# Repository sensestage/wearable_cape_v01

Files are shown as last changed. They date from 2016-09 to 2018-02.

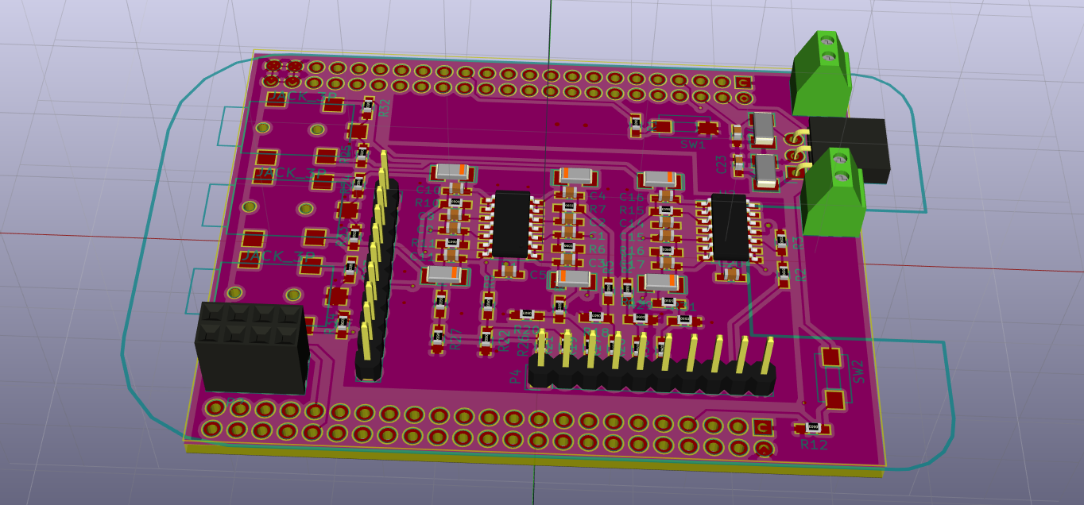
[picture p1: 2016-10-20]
wearable_cape_v0.2.png

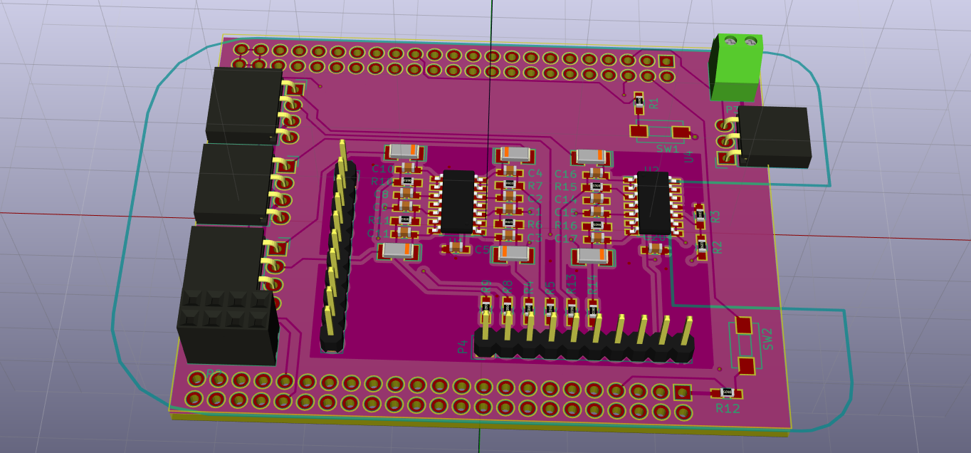
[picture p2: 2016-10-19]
wearable_cape.png

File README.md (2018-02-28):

# wearable_cape_v01

First version of a wearable cape for the VanAbbemuseum Earthquake Archive

## ToDos

### Minor fixes for v02

- fix wiring errors on minijack outputs to amplifiers
- Swap out the buffered voltage divider 1.8V reference for a fixed regulator
- Add bypass capacitors to the active filters
- widen power rail traces to the amplifier boards
- silkscreen labels for switch functionality and outputs
- breakout capability of mode switch, reset switch, & status LEDs
  - user leds, see: http://beaglebone.cameon.net/home/using-the-user-leds

### Larger improvements

- add additional 2-channel output for full access to all output channels

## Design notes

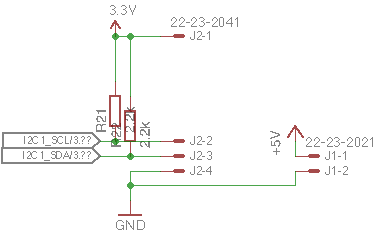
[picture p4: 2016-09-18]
Documentation/Bela_Cape_Schematic04.png

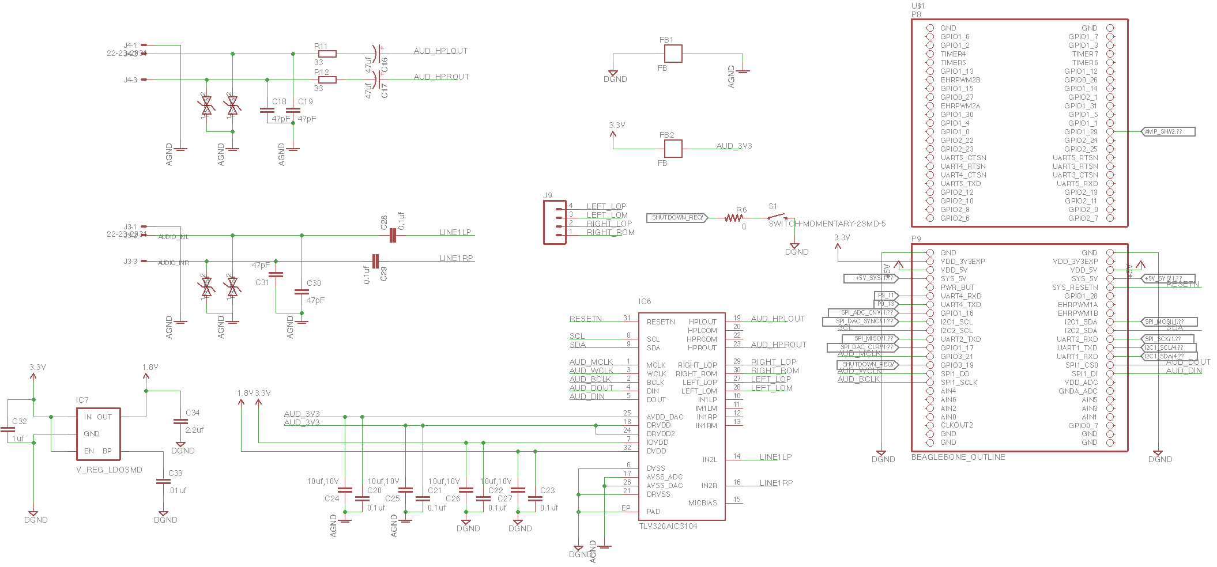
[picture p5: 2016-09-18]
Documentation/Bela_Cape_Schematic03.png

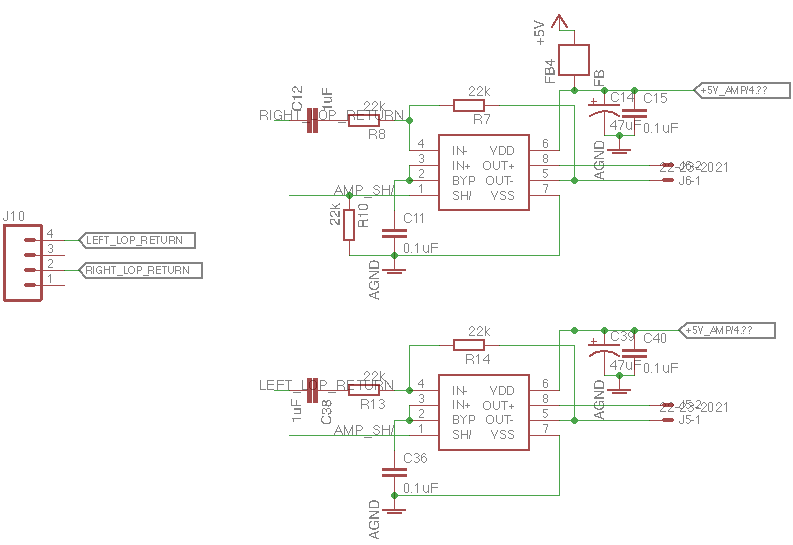
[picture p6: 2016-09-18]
Documentation/Bela_Cape_Schematic02.png

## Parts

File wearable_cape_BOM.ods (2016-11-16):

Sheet: References
Reference | Value | Library | Library Ref
R1 | 100 | device | R
C20 | 100nF | device | C
C5 | 100nF | device | C
R12 | 10k | device | R
R2 | 120k | device | R
C12 | 1uF | device | CP1
C13 | 1uF | device | CP1
C18 | 1uF | device | CP1
C19 | 1uF | device | CP1
C6 | 1uF | device | CP1
C7 | 1uF | device | CP1
C1 | 220pF | device | C
C14 | 220pF | device | C
C15 | 220pF | device | C
C2 | 220pF | device | C
C8 | 220pF | device | C
C9 | 220pF | device | C
R10 | 28.7k | device | R
R11 | 28.7k | device | R
R13 | 28.7k | device | R
R14 | 28.7k | device | R
R15 | 28.7k | device | R
R16 | 28.7k | device | R
R4 | 28.7k | device | R
R5 | 28.7k | device | R
R6 | 28.7k | device | R
R7 | 28.7k | device | R
R8 | 28.7k | device | R
R9 | 28.7k | device | R
C10 | 440pF | device | C
C11 | 440pF | device | C
C16 | 440pF | device | C
C17 | 440pF | device | C
C3 | 440pF | device | C
C4 | 440pF | device | C
R3 | 68k | device | R
P3 | BATTERY | conn | CONN_01X02
U3 | BEAGLEBONEBLACK | beagleboneblack | BEAGLEBONEBLACK
P1 | BELA_AINS | wearable_cape | BELA_AINS
P4 | BELA_AOUTS | wearable_cape | BELA_AOUTS
P5 | CONN_01X04 | conn | CONN_01X04
P6 | CONN_01X04 | conn | CONN_01X04
P7 | CONN_01X04 | conn | CONN_01X04
U1 | MCP6004 | linear | MCP6004
U2 | MCP6004 | linear | MCP6004
U4 | OKI_7805 | oki_7805 | OKI_7805
P2 | RECEIVER | conn | CONN_02X04
SW1 | SW_HALT | device | SW_PUSH
SW2 | SW_MODE_SEL | device | SW_PUSH
C21 | CP1 | device | CP1
C22 | CP1 | device | CP1
P5 | PWR_OUT | conn | CONN_01X02
J1 | JACK_3P | jack_3p | JACK_3P
J2 | JACK_3P | jack_3p | JACK_3P
J3 | JACK_3P | jack_3p | JACK_3P
C23 | C | device | C
C24 | C | device | C
R23 | 100k | device | R
R25 | 100k | device | R
R24 | 100k | device | R
R34 | 100k | device | R
R32 | 100k | device | R
R33 | 100k | device | R
R19 | 150k | device | R
R20 | 200k | device | R
R17 | 150k | device | R
R18 | 200k | device | R
R21 | 150k | device | R
R22 | 200k | device | R
R30 | 150k | device | R
R31 | 200k | device | R
R28 | 150k | device | R
R29 | 200k | device | R
R26 | 150k | device | R
R27 | 200k | device | R

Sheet: BOM
 |  |  |  |  |  |  |  |  |  | € 83,7804 | boards | 4
References | Value | Amount | Footprint | Supplier | Supplier part no | Cost/unit | Cost/N | N | Minimum N | Total cost / board | in stock (pre 15-11) | needed | Part no. | to order | Ordered 7-11 | Ordered 15-11
R1 | 100 | 1 | R0603 | Farnell | 2447227 | € 0,0035 | € 0,04 | 10 | 10 | € 0,0035 | 10 | 4 | 2447227 | 0 | 10
R18, R20, R22, R27, R29, R31 | 390 | 6 | R0603 | Farnell | 2447353 | € 0,0035 | € 0,04 | 10 | 10 | € 0,0210 | 20 | 24 | 2447353 | 4 | 20 | 10
R17, R19, R21, R26, R28, R30 | 2k2 | 6 | R0603 | Farnell | 2447320 | € 0,0035 | € 0,04 | 10 | 10 | € 0,0210 | 20 | 24 | 2447320 | 4 | 20 | 10
R23, R24, R25, R32, R33, R34 | 3k9 | 6 | R0603 | Farnell | 2447359 | € 0,0035 | € 0,04 | 10 | 10 | € 0,0210 | 20 | 24 | 2447359 | 4 | 20 | 10
R12 | 10k | 1 | R0603 | Farnell | 2447230 | € 0,0035 | € 0,04 | 10 | 10 | € 0,0035 | 10 | 4 | 2447230 | 0 | 10
R35, R36, R37, R38, R39, R40 | 12k | 6 | R0603 | Farnell | 2447243 | € 0,0035 | € 0,04 | 10 | 10 | € 0,0210 | 20 | 24 | 2447243 | 4 | 20 | 10
R2 | 120k | 1 | R0603 | Farnell | 2447239 | € 0,0035 | € 0,04 | 10 | 10 | € 0,0035 | 10 | 4 | 2447239 | 0 | 10
R10, R11, R13, R14, R15, R16, R4, R5, R6, R7, R8, R9 | 28.7k | 12 | R0603 | Farnell | 2447318 | € 0,0036 | € 0,04 | 10 | 10 | € 0,0432 | 40 | 48 | 2447318 | 8 | 40 | 10
R3 | 68k | 1 | R0603 | Farnell | 2447420 | € 0,0035 | € 0,04 | 10 | 10 | € 0,0035 | 10 | 4 | 2447420 | 0 | 10
 | 100k | 0 | R0603 | Farnell | 2447226 | € 0,0035 | € 0,04 | 10 | 10 | € 0,0000 |  | 0 | 2447226 | 0
 | 150k | 0 | R0603 | Farnell | 2447254 | € 0,0037 | € 0,04 | 10 | 10 | € 0,0000 |  | 0 | 2447254 | 0
 | 200k | 0 | R0603 | Farnell | 2447291 | € 0,0035 | € 0,04 | 10 | 10 | € 0,0000 |  | 0 | 2447291 | 0
FB1, FB2 | Ferrite bead | 2 | R0603 | Farnell | 1781090 | € 0,0608 | € 0,06 | 1 | 10 | € 0,1216 | 10 | 8 | 1781090 | 0 | 10
C5, C20 | 100nF | 2 | C0603 | Farnell | 1740612 | € 0,0531 | € 0,53 | 10 | 10 | € 0,1062 | 10 | 8 | 1740612 | 0 | 10
C6, C7, C12, C13, C18, C19 | 1uF | 6 | C1206 | Farnell | 1759436 | € 0,0587 | € 0,59 | 10 | 10 | € 0,3522 | 20 | 24 | 1759436 | 4 | 20 | 10
C1, C2, C8, C9, C14, C15 | 220pF | 6 | C0603 | Farnell | 430948 | € 0,0369 | € 0,04 | 1 | 10 | € 0,2214 | 20 | 24 | 430948 | 4 | 20 | 10
C3, C4, C10, C11, C16, C17 | 440pF / in fact 470 pF | 6 | C0603 | Farnell | 2496906 | € 0,0241 | € 0,02 | 1 | 10 | € 0,1446 | 20 | 24 | 2496906 | 4 | 20 | 10
C21, C22 | 10uF | 2 | C1210 | Farnell | 2320922 | € 0,0795 | € 0,80 | 10 | 10 | € 0,1590 | 10 | 8 | 2320922 | 0 | 10
C23, C24 | 100 nF | 2 | C0603 | Farnell | 1740612 | € 0,0531 | € 0,53 | 10 | 10 | € 0,1062 | 10 | 8 | 1740612 | 0 | 10
U1, U2 | MCP6004 | 2 | SOIC14 | Farnell | 1605572 | € 0,3400 | € 3,40 | 10 | 10 | € 0,6800 | 10 | 8 | 1605572 | 0
U4 | OKI_7805 | 1 | 3 pin | Farnell | 1668339 | € 0,8820 | € 0,88 | 1 | 1 | € 0,8820 | 3 | 4 | 1668339 | 1 | 2 | 1
U3 | BEAGLEBONEBLACK | 2 | Beaglebone pin headers | Farnell | 2505042 | € 2,2400 | € 2,24 | 1 | 5 | € 4,4800 | 10 | 8 | 2505042 | 0 | 10
P1, P4 | 10 pin header | 1 |  | Farnell | 1022259 | € 0,3260 | € 0,33 | 1 | 10 | € 0,3260 | 10 | 4 | 1022259 | 0 | 10
SW1, SW2 | SW_HALT, SW_MODE_SEL | 2 |  | Farnell | 2079522 | € 0,4790 | € 0,48 | 1 | 1 | € 0,9580 | 6 | 8 | 2079522 | 2 | 5 | 2
P3 | BATTERY | 1 | screw terminal, 3.5MM | (from amplifier kit) |  |  |  |  |  | € 0,0000 |  | 4 | 0 | 4
P5 | PWR_OUT | 1 | screw terminal | Farnell | 2112482 | € 1,0100 | € 1,01 | 1 | 1 | € 1,0100 | 3 | 4 | 2112482 | 1 | 2 | 1
P2 | RECEIVER / 8 pin connector | 1 | IDC connector | Farnell | 2215303 | € 0,5720 | € 0,57 | 1 | 1 | € 0,5720 | 3 | 4 | 2215303 | 1 | 2 | 1
J1, J2, J3 | headphone connector | 3 |  | Farnell | 1216980 | € 1,0900 | € 10,90 | 10 | 10 | € 3,2700 | 10 | 12 | 1216980 | 2 |  | 2
External components
voltage regulator | OKI-78SR-5/1.5-W36-C | 1 |  | Farnell | 2102101 | € 7,3500 |  |  |  | € 7,3500 | 4 | 4 | 2102101 | 0
Amplifier board | Stereo 20W amp, MAX9744 | 3 |  | Kiwi Electronics | ADA-1752 | € 19,2000 | € 192,00 | 10 | 10 | € 57,6000 | 10 | 12
DC barrel cable |  | 1 |  | Bax electronics | http://www.bax-shop.nl/gitaareffect-voeding-adapter/mooer-pdc-5a-daisy-chain-dc-power-cable | € 5,3000 |  |  |  | € 5,3000 | 3 | 4
audio cable minijack – minijack |  | 3 |  | Bax electronics | http://www.bax-shop.nl/index.php?Itemid=2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 | € 1,5300 |  |  |  | € 4,5900 | 9 | 12
Distance screws for amplifier boards |  | 8 |  | Farnell | 2345351 | € 0,4640 | € 0,46 | 1 | 1 | € 1,3920 | 1 | 32 | 2345351 | 31 | 23
Distance screws for amplifier boards |  | 8 |  | Farnell | 2311419 | € 0,7820 | € 0,78 | 1 | 10 | € 6,2560 | 1 | 32 | 2311419 | 31 | 23
Distance screws for amplifier boards |  | 8 |  | Farnell | 2494522 | € 0,0810 | € 0,08 | 1 | 10 | € 0,6480 | 10 | 32 | 2494522 | 22 | 20
IDC cable to receiver |  | 1 |  | Farnell | 2217620 | € 2,3700 |  |  |  | € 2,3700 | 1 | 4 | 2217620 | 3 | 2
BATTERY
cables HXT to wire |  | 1 |  | Hobby King | http://www.hobbyking.com/hobbyking/store/__24423__HXT4mm_w_12AWG_Silicon_Wire_10cm_ESC_side_5pcs_Bag_.html
5000 mAh battery |  | 1 |  | Hobby King | http://www.hobbyking.com/hobbyking/store/uh_viewitem.asp?idproduct=35834
HXT to bananaplug adapter |  | 1 |  | Hobby King | https://www.hobbyking.com/hobbyking/store/uh_viewItem.asp?idProduct=31487
low battery warning circuit |  | 1 |  | Hobby King | http://www.hobbyking.com/hobbyking/store/__41734__HobbyKing_8482_Lipoly_Low_Voltage_Alarm_2s_3s_EU_Warehouse_.html
battery charger |  | 1 |  | Hobby King | https://www.hobbyking.com/hobbyking/store/uh_viewItem.asp?idProduct=95979

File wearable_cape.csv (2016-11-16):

Reference | Value | Footprint | Datasheet
U3 | BEAGLEBONEBLACK | BBB:beagleboneblack_nomount
SW1 | SW_HALT | Buttons_Switches_SMD:SW_SPST_EVQPE1
SW2 | SW_MODE_SEL | Buttons_Switches_SMD:SW_SPST_EVQPE1
C20 | 100nF | Capacitors_SMD:C_0603_HandSoldering
C5 | 100nF | Capacitors_SMD:C_0603_HandSoldering
C1 | 220pF | Capacitors_SMD:C_0603_HandSoldering
C14 | 220pF | Capacitors_SMD:C_0603_HandSoldering
C15 | 220pF | Capacitors_SMD:C_0603_HandSoldering
C2 | 220pF | Capacitors_SMD:C_0603_HandSoldering
C8 | 220pF | Capacitors_SMD:C_0603_HandSoldering
C9 | 220pF | Capacitors_SMD:C_0603_HandSoldering
C10 | 440pF | Capacitors_SMD:C_0603_HandSoldering
C11 | 440pF | Capacitors_SMD:C_0603_HandSoldering
C16 | 440pF | Capacitors_SMD:C_0603_HandSoldering
C17 | 440pF | Capacitors_SMD:C_0603_HandSoldering
C3 | 440pF | Capacitors_SMD:C_0603_HandSoldering
C4 | 440pF | Capacitors_SMD:C_0603_HandSoldering
C23 | C | Capacitors_SMD:C_0603_HandSoldering
C24 | C | Capacitors_SMD:C_0603_HandSoldering
U1 | MCP6004 | Housings_SOIC:SOIC-14_3.9x8.7mm_Pitch1.27mm
U2 | MCP6004 | Housings_SOIC:SOIC-14_3.9x8.7mm_Pitch1.27mm
P2 | RECEIVER | IDC_header_8pin:IDC_Header_Straight_10pins
J1 | JACK_3P | Lumberg:Lumberg_1503_03
J2 | JACK_3P | Lumberg:Lumberg_1503_03
J3 | JACK_3P | Lumberg:Lumberg_1503_03
P1 | BELA_AINS | Pin_Headers:Pin_Header_Straight_1x10
P4 | BELA_AOUTS | Pin_Headers:Pin_Header_Straight_1x10
R1 | 100 | Resistors_SMD:R_0603_HandSoldering
R18 | 390 | Resistors_SMD:R_0603_HandSoldering
R20 | 390 | Resistors_SMD:R_0603_HandSoldering
R22 | 390 | Resistors_SMD:R_0603_HandSoldering
R27 | 390 | Resistors_SMD:R_0603_HandSoldering
R29 | 390 | Resistors_SMD:R_0603_HandSoldering
R31 | 390 | Resistors_SMD:R_0603_HandSoldering
R12 | 10k | Resistors_SMD:R_0603_HandSoldering
R2 | 120k | Resistors_SMD:R_0603_HandSoldering
R35 | 12k | Resistors_SMD:R_0603_HandSoldering
R36 | 12k | Resistors_SMD:R_0603_HandSoldering
R37 | 12k | Resistors_SMD:R_0603_HandSoldering
R38 | 12k | Resistors_SMD:R_0603_HandSoldering
R39 | 12k | Resistors_SMD:R_0603_HandSoldering
R40 | 12k | Resistors_SMD:R_0603_HandSoldering
R10 | 28.7k | Resistors_SMD:R_0603_HandSoldering
R11 | 28.7k | Resistors_SMD:R_0603_HandSoldering
R13 | 28.7k | Resistors_SMD:R_0603_HandSoldering
R14 | 28.7k | Resistors_SMD:R_0603_HandSoldering
R15 | 28.7k | Resistors_SMD:R_0603_HandSoldering
R16 | 28.7k | Resistors_SMD:R_0603_HandSoldering
R4 | 28.7k | Resistors_SMD:R_0603_HandSoldering
R5 | 28.7k | Resistors_SMD:R_0603_HandSoldering
R6 | 28.7k | Resistors_SMD:R_0603_HandSoldering
R7 | 28.7k | Resistors_SMD:R_0603_HandSoldering
R8 | 28.7k | Resistors_SMD:R_0603_HandSoldering
R9 | 28.7k | Resistors_SMD:R_0603_HandSoldering
R17 | 2k2 | Resistors_SMD:R_0603_HandSoldering
R19 | 2k2 | Resistors_SMD:R_0603_HandSoldering
R21 | 2k2 | Resistors_SMD:R_0603_HandSoldering
R26 | 2k2 | Resistors_SMD:R_0603_HandSoldering
R28 | 2k2 | Resistors_SMD:R_0603_HandSoldering
R30 | 2k2 | Resistors_SMD:R_0603_HandSoldering
R23 | 3k9 | Resistors_SMD:R_0603_HandSoldering
R24 | 3k9 | Resistors_SMD:R_0603_HandSoldering
R25 | 3k9 | Resistors_SMD:R_0603_HandSoldering
R32 | 3k9 | Resistors_SMD:R_0603_HandSoldering
R33 | 3k9 | Resistors_SMD:R_0603_HandSoldering
R34 | 3k9 | Resistors_SMD:R_0603_HandSoldering
R3 | 68k | Resistors_SMD:R_0603_HandSoldering
FB1 | FILTER | Resistors_SMD:R_0603_HandSoldering
FB2 | FILTER | Resistors_SMD:R_0603_HandSoldering
C12 | 1uF | SMD_Packages:SMD-1206_Pol
C13 | 1uF | SMD_Packages:SMD-1206_Pol
C18 | 1uF | SMD_Packages:SMD-1206_Pol
C19 | 1uF | SMD_Packages:SMD-1206_Pol
C6 | 1uF | SMD_Packages:SMD-1206_Pol
C7 | 1uF | SMD_Packages:SMD-1206_Pol
C21 | CP1 | SMD_Packages:SMD-1210_Pol
C22 | CP1 | SMD_Packages:SMD-1210_Pol
U4 | OKI_7805 | Socket_Strips:Socket_Strip_Angled_1x03
P5 | PWR_OUT | Terminal_Blocks:TerminalBlock_Pheonix_MPT-2.54mm_2pol
P3 | BATTERY | Terminal_Blocks:TerminalBlock_Pheonix_PT-3.5mm_2pol

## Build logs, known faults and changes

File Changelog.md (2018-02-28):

28-02-2018:
- fixed the pinout of the jack plugs.
    - Some components may have shifted very slightly.
    - The ordering of the outputs has altered
- the labeling of the pins from the BELA_OUT* to A_FILT_OUT* is now consistent

Mistakes on PCB v0.3

* pinouts of jack plugs. Pin 1 should be GND and pin 2 signal.
* numbering of filtouts inconsistent

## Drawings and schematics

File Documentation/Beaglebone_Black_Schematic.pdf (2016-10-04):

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
## 8 eMMC FLASH

2

3

## 9 10/100 ETHERNET HDMI FRAMER 10

## PROCESSOR 2 OF 3, UAB PORTS

## DDR3 MEMORY 7

## LED, CONFIGURATION AND BUTTON

SCHEMATIC PAGE PAGE NO.

## PROCESSOR 1 OF 3, JTAG HEADER

## PROCESSOR 3 OF 3

4

## POWER MANAGEMENT

5

## COVER PAGE

6

This schematic is *NOT SUPPORTED* and DOES NOT constitute

a reference design. Only “community” support is allowed

via resources at BeagleBoard.org/discuss.

THERE IS NO WARRANTY FOR THIS DESIGN , TO THE EXTENT

PERMITTED BY APPLICABLE LAW. EXCEPT WHEN OTHERWISE STATED

IN WRITING THE COPYRIGHT HOLDERS AND/OR OTHER PARTIES

PROVIDE THE DESIGN “AS IS” WITHOUT WARRANTY OF ANY KIND,
EITHER EXPRESSED OR IMPLIED, INCLUDING, BUT NOT LIMITED

TO, THE IMPLIED WARRANTIES OF MERCHANTABILITY AND FITNESS

FOR A PARTICULAR PURPOSE. THE ENTIRE RISK AS TO THE

QUALITY AND PERFORMANCE OF THE DESIGN IS WITH YOU. SHOULD

THE DESIGN PROVE DEFECTIVE, YOU ASSUME THE COST OF ALL

NECESSARY SERVICING, REPAIR OR CORRECTION.

## 11 EXP CONN, uSD

# NOTE: PCB Revision for this board is Rev B6

## REV BY Description DATE

### GC 11/19/2012 Initial production Release. A4A

A5 On the initial production release the processors were to be found incorrect as supplied by TI. Parts while marked AM3359 were actually AM3352. This revision uses the correct parts. 1/2/2013 GC

1. Deleted R29-R44 from the LCD lines.
2. Added 47pf capacitors C156-C173 to LCD data lines to ground.
3. Changed schematic revision to A5A.

A5A

4. Changed a few footprints after PCB update for above changes.

# 5. Added access point for the battery function of the TPS65217C. 2/8/2013 GC

6. Added Ferrite beads in series with LED power and 5V power rail of the USB host
connector. Required to pass FCC/CE testing due to noise emissions on that pin.
7. Added power button to enable sleep, wakeup, power down and power up features on the

system.

A5B 1. Added 100K pulldown on J1 pin 4 to prevent crosstalk when serial cable is not connected into PCB layout.

2. Changed the LED resistors to 4.75K to lower the brightness.

5/21/2013

8. Added Modification to add 100K ohm resistor to ground to prvent crosstalk when serial

cable is not plugged in.

GC

A5C

6/12/2013 GC

1. Changed R46, R47,R48 to 0 ohms.
2. Changed R45 to 22 Ohms.

Change was made due to production failures on some boards due to differences in impedances.

A6

1. Moved the enable for the VDD_3V3B regulator to VDD_3V3A rail. Change was made to

reduce the delay between the ramp up of the 3.3V rails.

7/25/2013 GC 2. Added a AND gate to the SYS_RESETn circuitry. There is a small chance that on power up the nRESETOUT signal on the processor may go high, causing the SYS_RESETn signal to go

HI before it should. This change reenforces the reset with the PORZn reset signal.

3. Added optional zero ohm resistor to tie GND_OSC0 to system ground.

A6A

GC 12/13/2013

1. Added optional zero ohm resistor to tie GND_OSC1 to system ground.
2. Changed C106 to a 1uF capacitor.
3. Changed C24 to a 2.2uF capacitor.

B 1.Changed the processor to the AM3358BZCZ100. 1/20/2014 GC

4. Made R8 installed and R9 not installed.

C 3/21/2014 GC 1.Increased the eMMC from 2GB to 4GB.

Title

Size Document Number Rev

Date: Sheet of

450-5500-001 C

## BeagleBone Black Cover Page

B

## 1 11 Friday, March 21, 2014

Title

Size Document Number Rev

Date: Sheet of

450-5500-001 C

## BeagleBone Black Cover Page

B

## 1 11 Friday, March 21, 2014

Title

Size Document Number Rev

Date: Sheet of

450-5500-001 C

## BeagleBone Black Cover Page

B
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

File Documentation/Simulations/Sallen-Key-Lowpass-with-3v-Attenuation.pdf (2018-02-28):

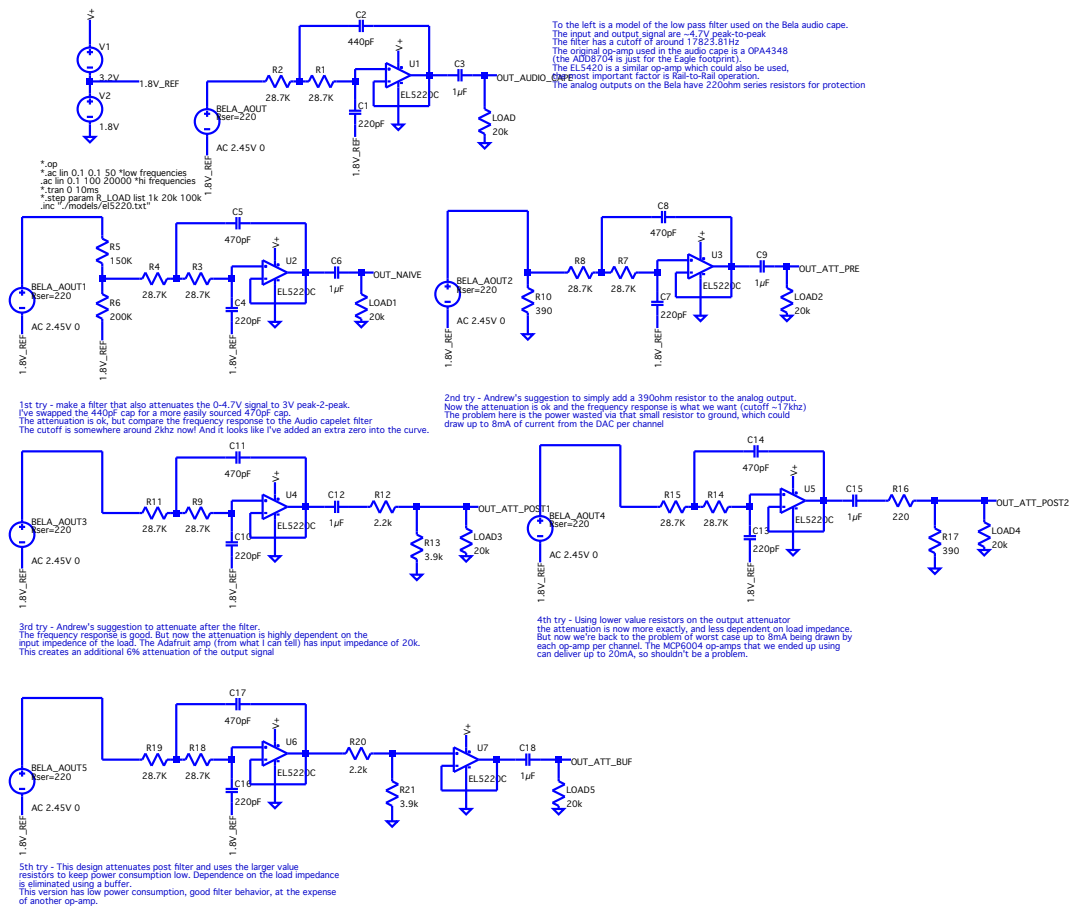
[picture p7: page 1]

To the left is a model of the low pass filter used on the Bela audio cape.
The input and output signal are ~4.7V peak-to-peak
The filter has a cutoff of around 17823.81Hz
The original op-amp used in the audio cape is a OPA4348
(the ADD8704 is just for the Eagle footprint).
The EL5420 is a similar op-amp which could also be used,
the most important factor is Rail-to-Rail operation.
The analog outputs on the Bela have 220ohm series resistors for protection

*.ac lin 0.1 0.1 50 *low frequencies
.ac lin 0.1 100 20000 *hi frequencies
*.tran 0 10ms
*.step param R_LOAD list 1k 20k 100k
.inc "./models/el5220.txt"

1st try - make a filter that also attenuates the 0-4.7V signal to 3V peak-2-peak.
I've swapped the 440pF cap for a more easily sourced 470pF cap.
The attenuation is ok, but compare the frequency response to the Audio capelet filter
The cutoff is somewhere around 2khz now! And it looks like I've added an extra zero into the curve.

2nd try - Andrew's suggestion to simply add a 390ohm resistor to the analog output.
Now the attenuation is ok and the frequency response is what we want (cutoff ~17khz)
The problem here is the power wasted via that small resistor to ground, which could
draw up to 8mA of current from the DAC per channel

3rd try - Andrew's suggestion to attenuate after the filter.
The frequency response is good. But now the attenuation is highly dependent on the
input impedence of the load. The Adafruit amp (from what I can tell) has input impedance of 20k.
This creates an additional 6% attenuation of the output signal

4th try - Using lower value resistors on the output attenuator
the attenuation is now more exactly, and less dependent on load impedance.
But now we're back to the problem of worst case up to 8mA being drawn by
each op-amp per channel. The MCP6004 op-amps that we ended up using
can deliver up to 20mA, so shouldn't be a problem.

5th try - This design attenuates post filter and uses the larger value
resistors to keep power consumption low. Dependence on the load impedance
is eliminated using a buffer.
This version has low power consumption, good filter behavior, at the expense
of another op-amp.

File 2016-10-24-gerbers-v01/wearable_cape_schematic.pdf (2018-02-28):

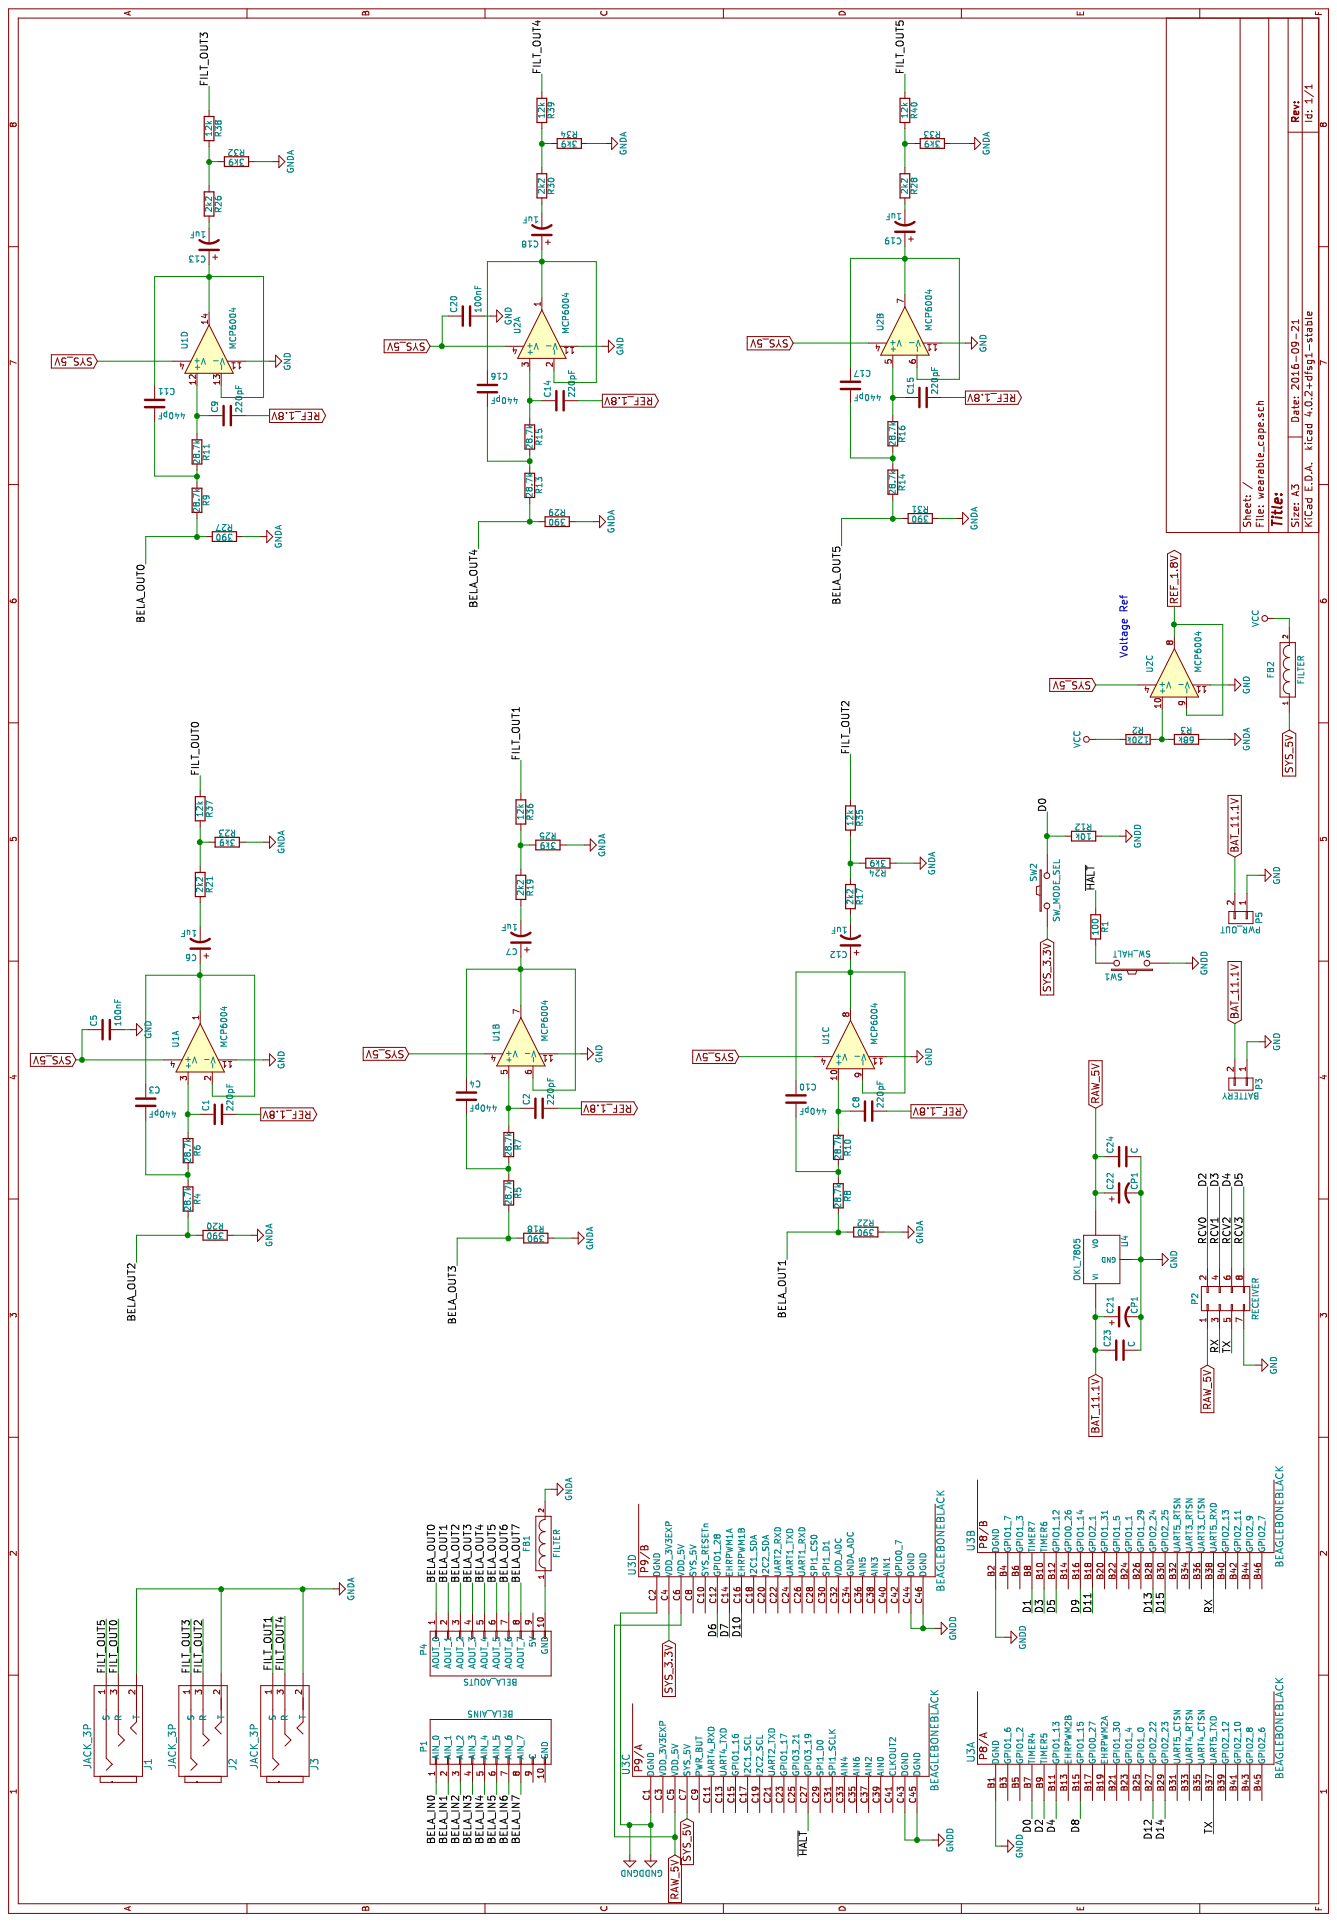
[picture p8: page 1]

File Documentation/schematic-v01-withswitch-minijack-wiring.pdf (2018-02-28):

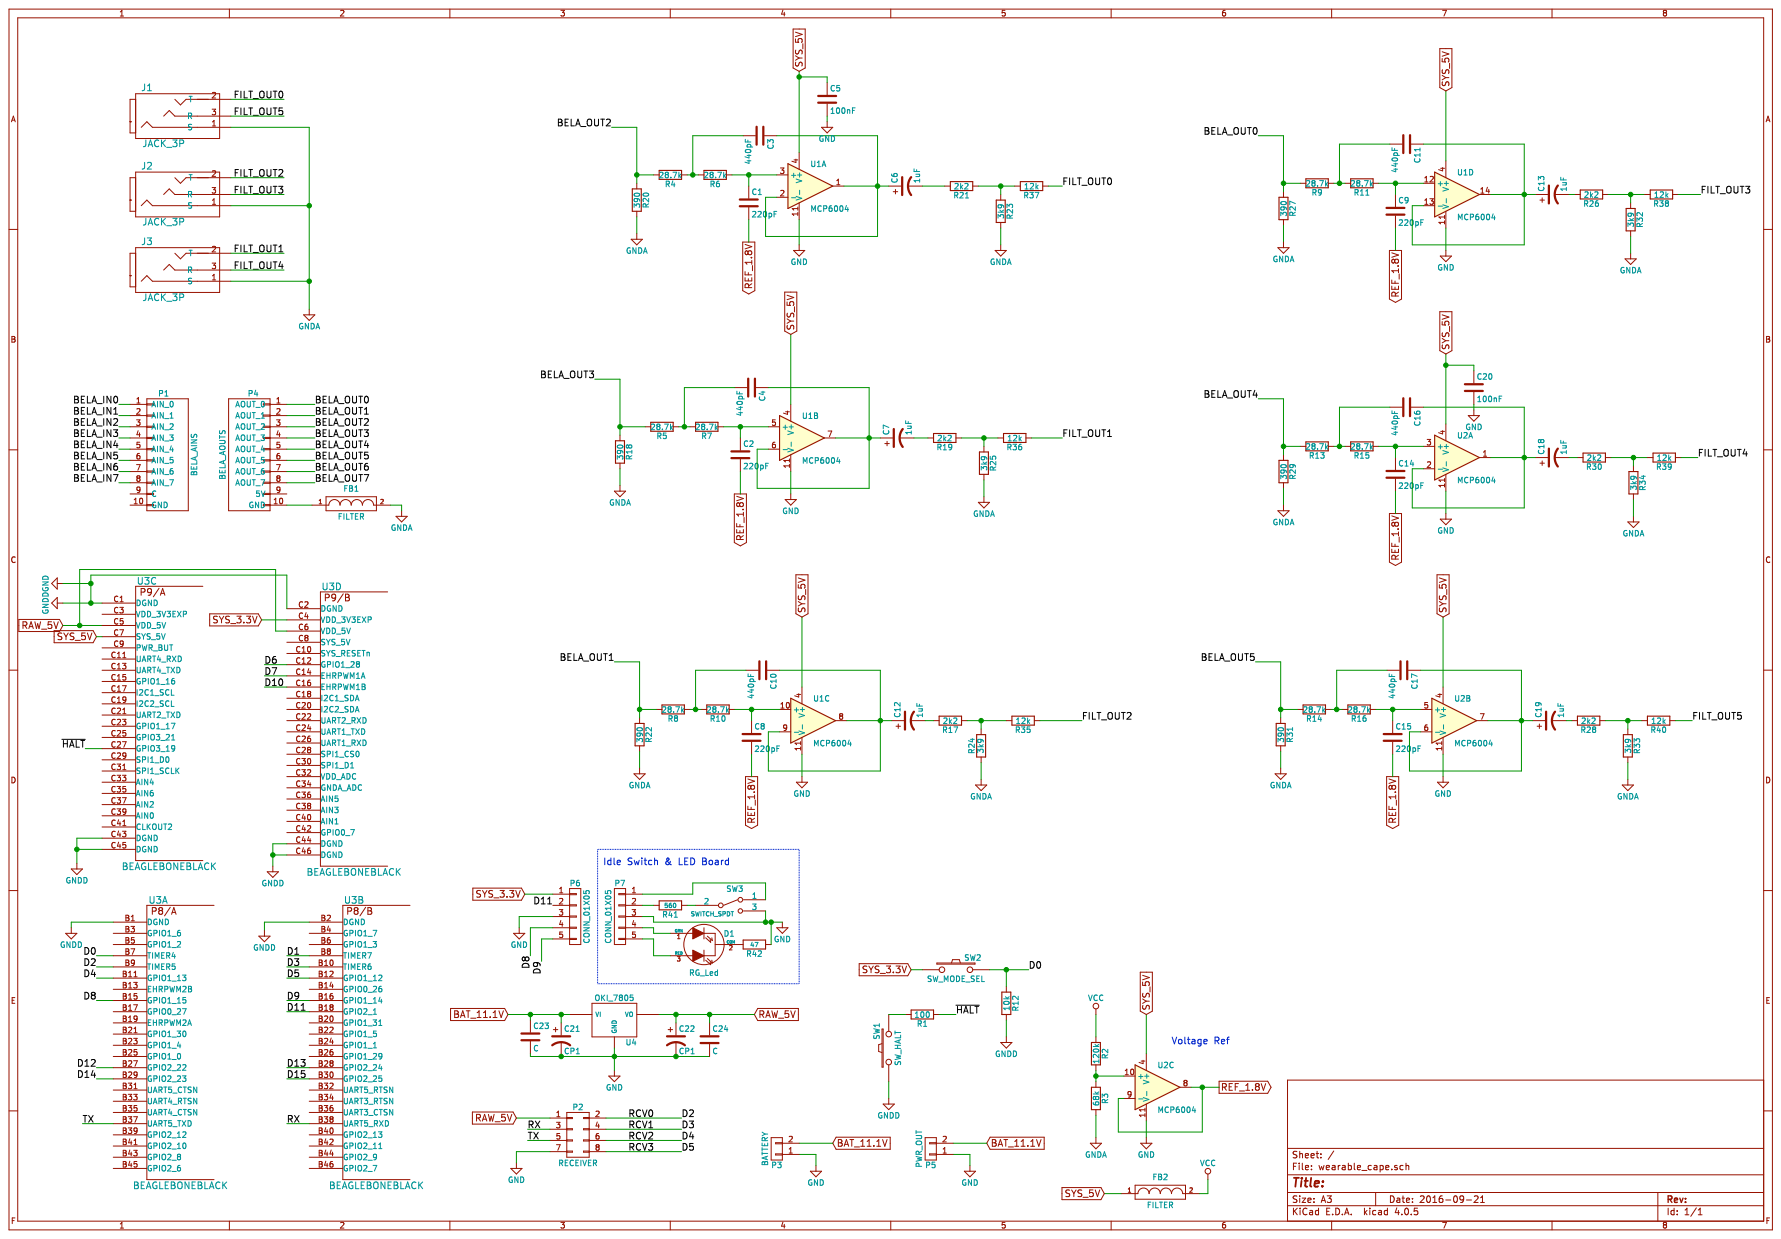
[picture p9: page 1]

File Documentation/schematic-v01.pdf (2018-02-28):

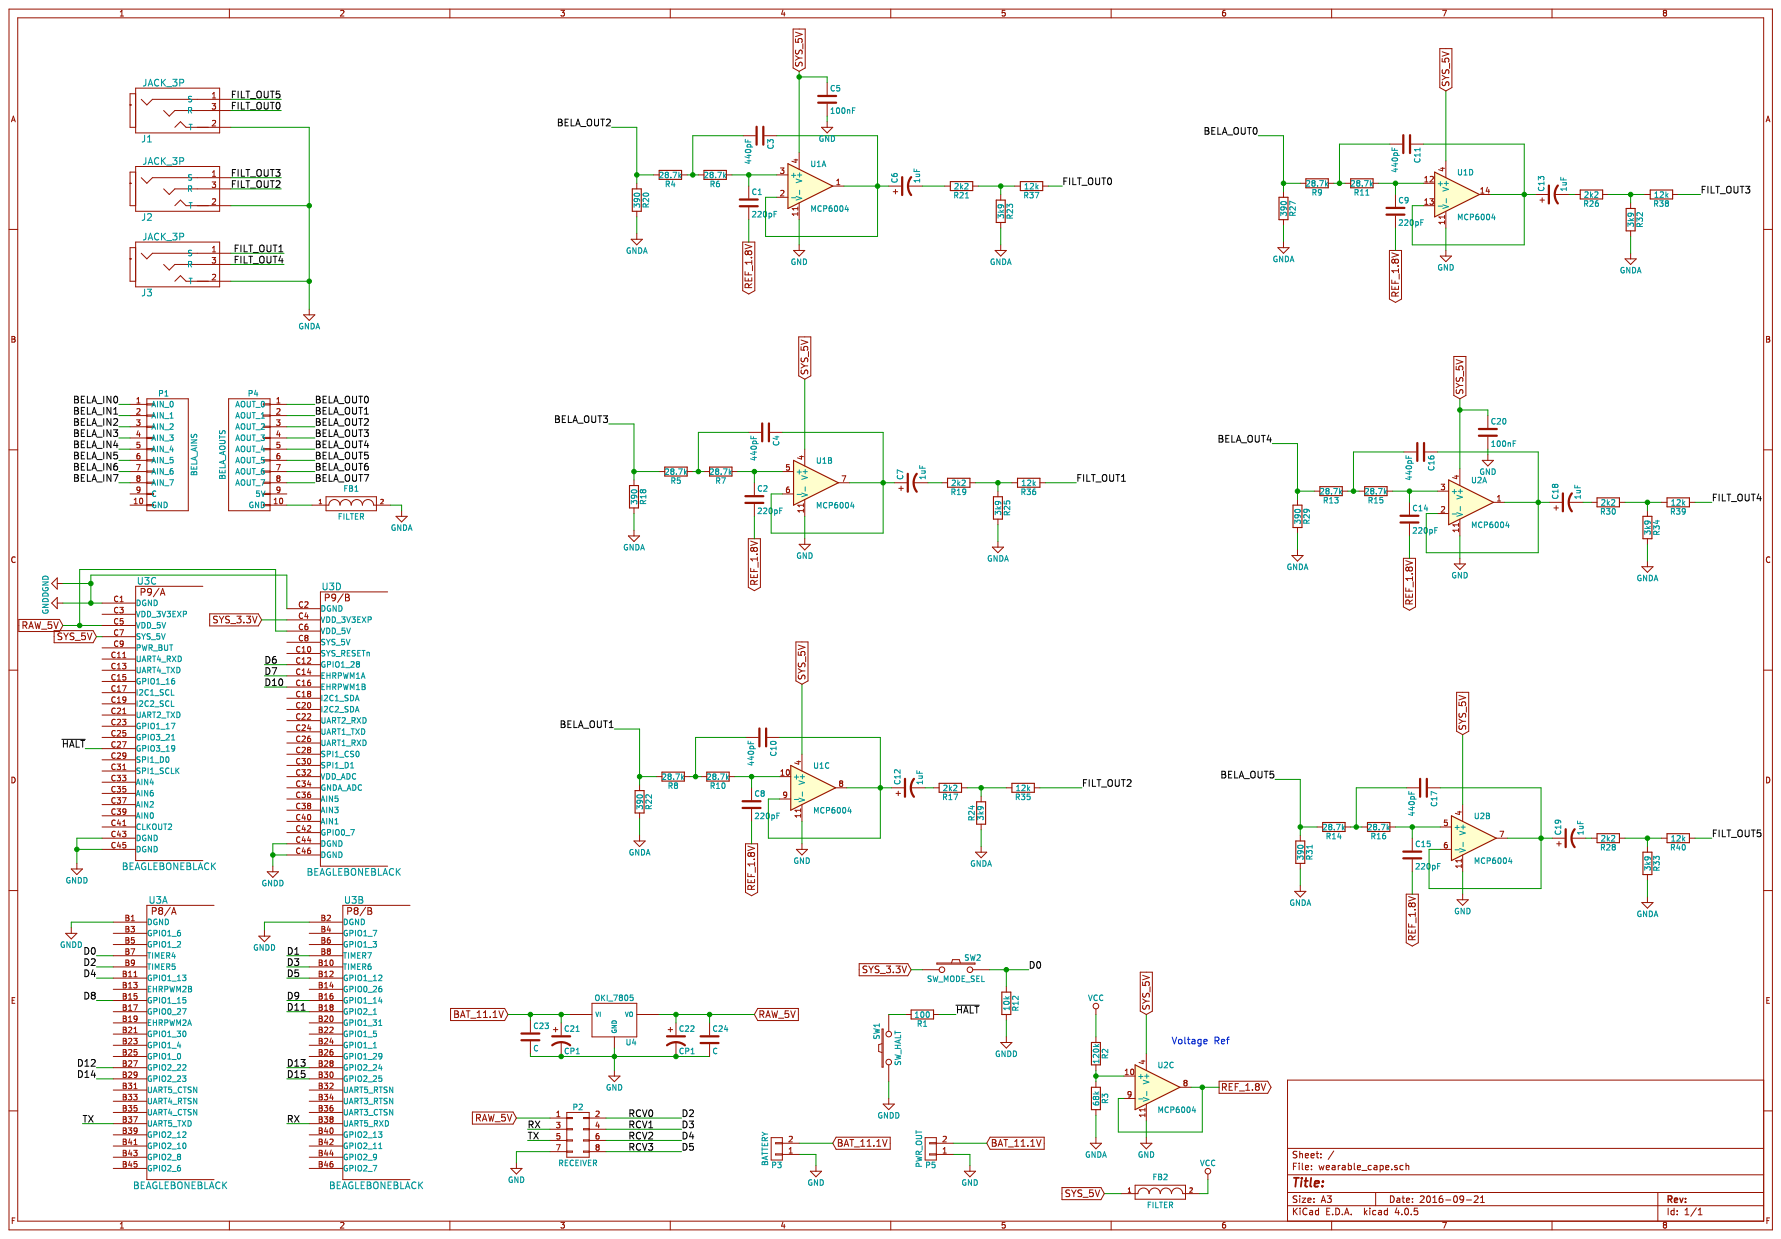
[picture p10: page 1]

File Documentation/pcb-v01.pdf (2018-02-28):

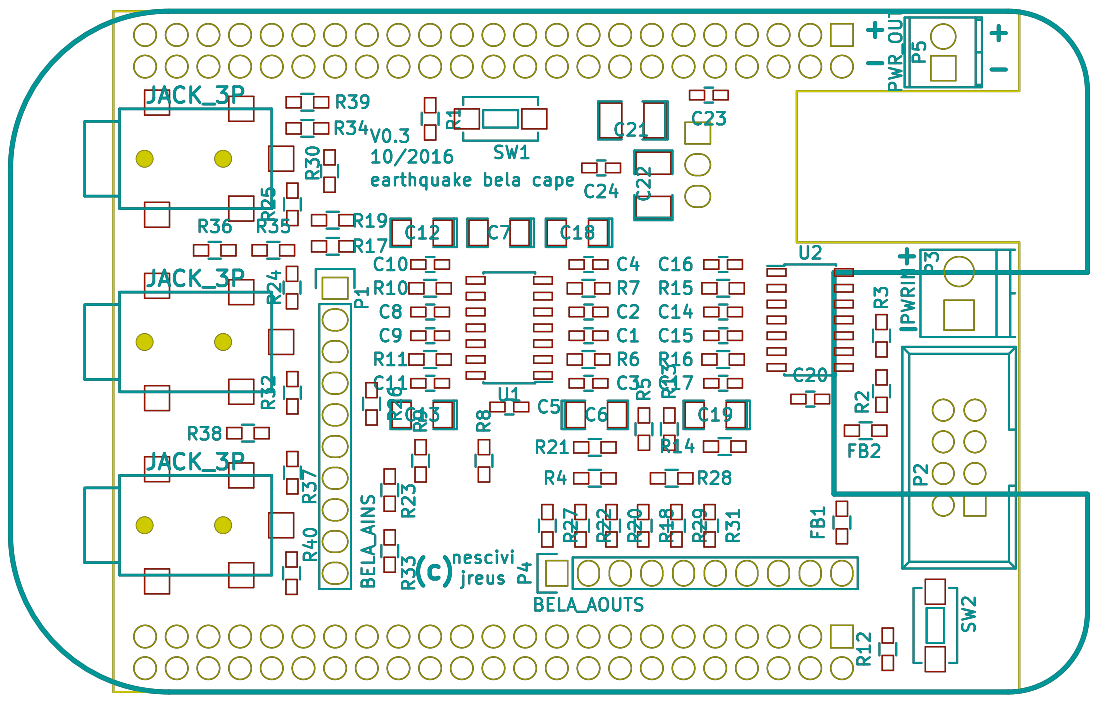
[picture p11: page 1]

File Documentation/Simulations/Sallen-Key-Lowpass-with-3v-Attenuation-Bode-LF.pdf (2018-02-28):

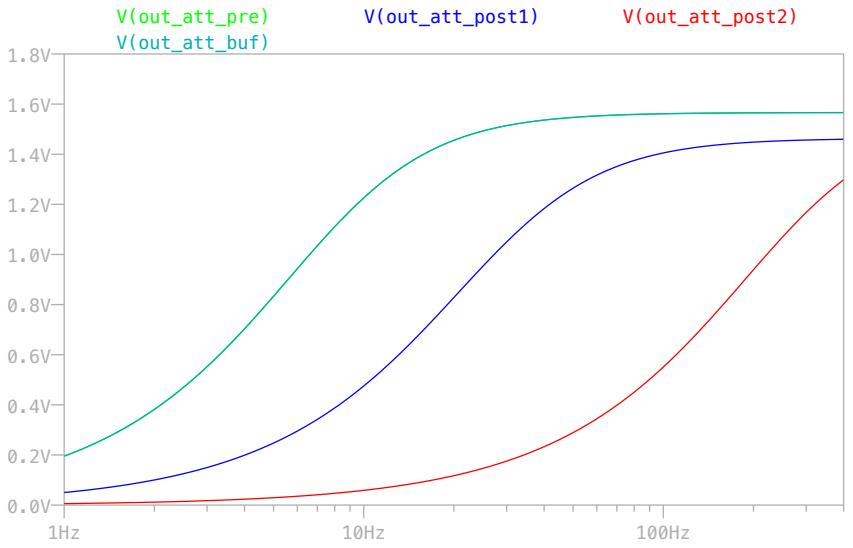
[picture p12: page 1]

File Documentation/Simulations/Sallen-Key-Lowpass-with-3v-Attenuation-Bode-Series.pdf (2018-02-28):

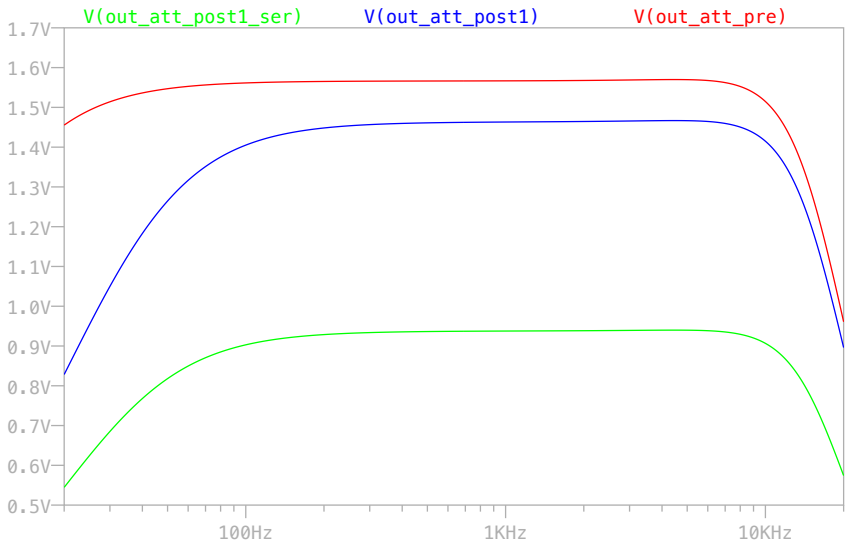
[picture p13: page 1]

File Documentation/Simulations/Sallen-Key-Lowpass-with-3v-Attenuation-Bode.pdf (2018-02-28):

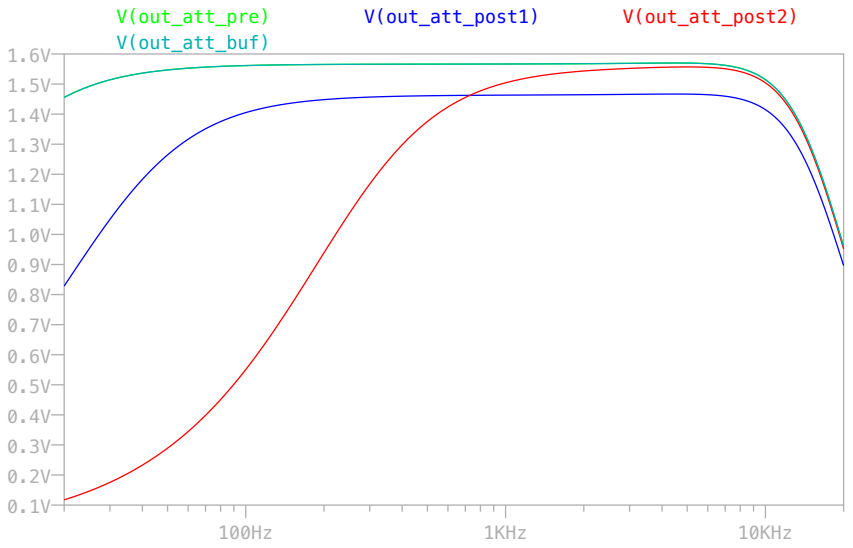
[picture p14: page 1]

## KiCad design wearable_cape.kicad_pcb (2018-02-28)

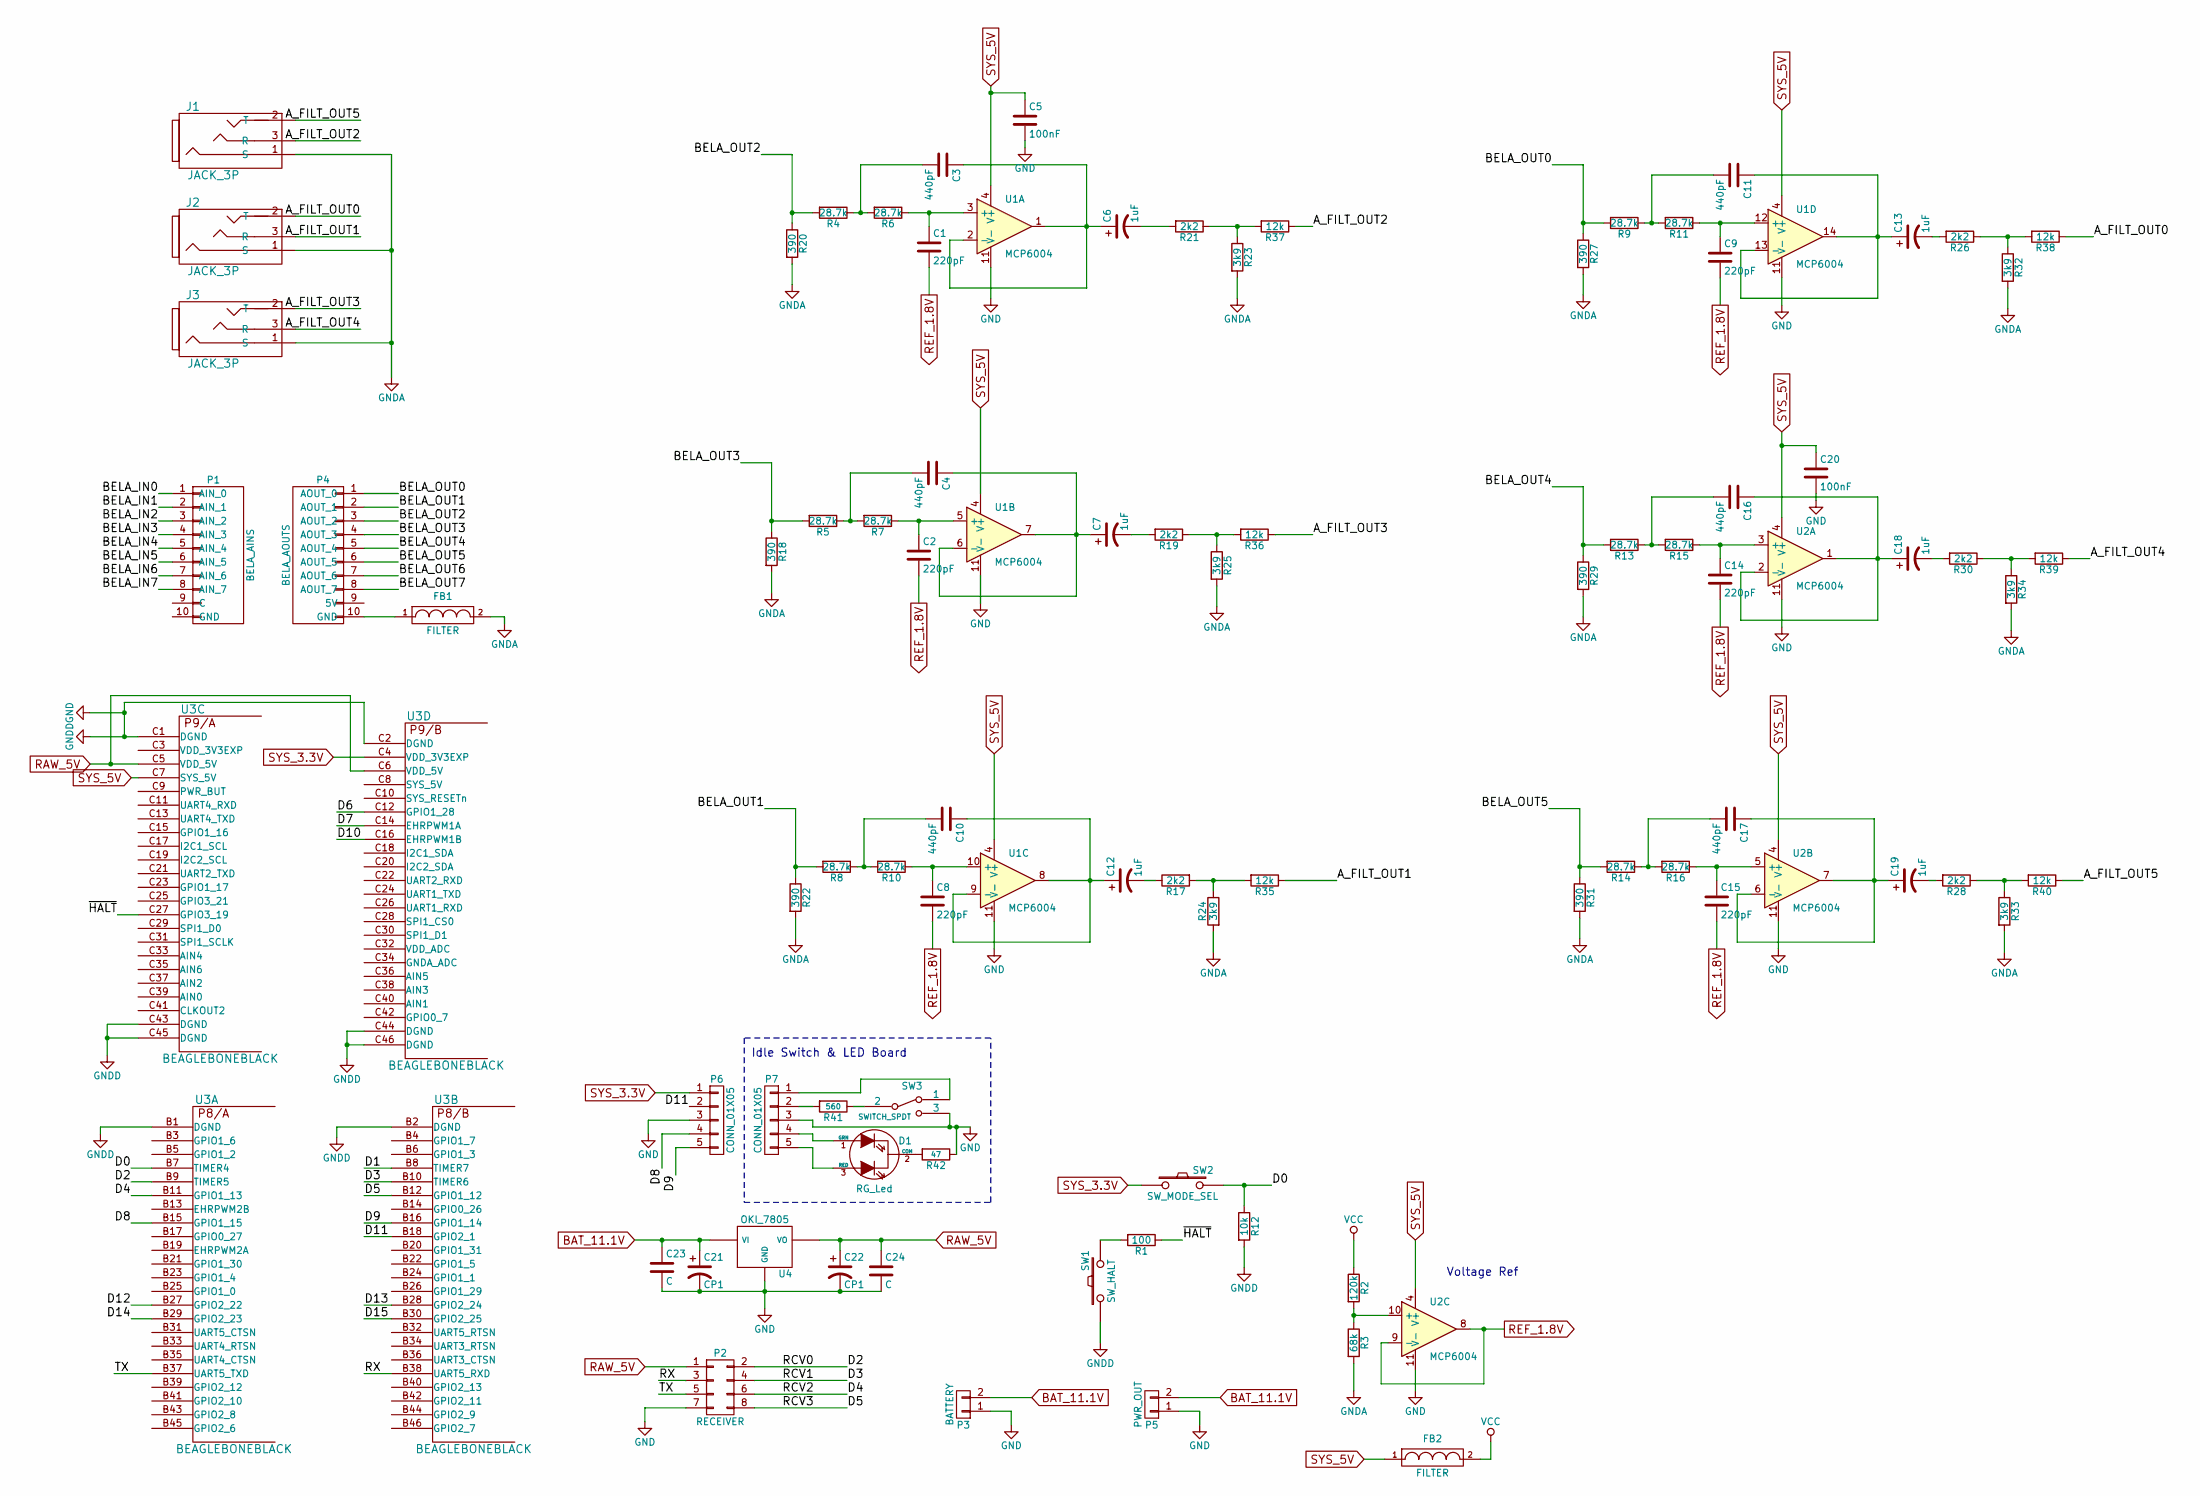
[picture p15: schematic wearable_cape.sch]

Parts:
C1, C2, C8, C9, C14, C15: 220pF; C_0603_HandSoldering
C3, C4, C10, C11, C16, C17: 440pF; C_0603_HandSoldering
C5, C20: 100nF; C_0603_HandSoldering
C6, C7, C12, C13, C18, C19: 1uF; SMD-1206_Pol
C21, C22: CP1; SMD-1210_Pol
C23, C24: C; C_0603_HandSoldering
D1: RG_Led
FB1, FB2: FILTER; R_0603_HandSoldering
J1, J2, J3: JACK_3P; Lumberg_1503_03
P1: BELA_AINS; Pin_Header_Straight_1x10
P2: RECEIVER; IDC_Header_Straight_10pins
P3: BATTERY; TerminalBlock_Pheonix_PT-3.5mm_2pol
P4: BELA_AOUTS; Pin_Header_Straight_1x10
P5: PWR_OUT; TerminalBlock_Pheonix_MPT-2.54mm_2pol
P6, P7: CONN_01X05
R1: 100; R_0603_HandSoldering
R2: 120k; R_0603_HandSoldering
R3: 68k; R_0603_HandSoldering
R4, R5, R6, R7, R8, R9, R10, R11, R13, R14, R15, R16: 28.7k; R_0603_HandSoldering
R12: 10k; R_0603_HandSoldering
R17, R19, R21, R26, R28, R30: 2k2; R_0603_HandSoldering
R18, R20, R22, R27, R29, R31: 390; R_0603_HandSoldering
R23, R24, R25, R32, R33, R34: 3k9; R_0603_HandSoldering
R35, R36, R37, R38, R39, R40: 12k; R_0603_HandSoldering
R41: 560
R42: 47
SW1: SW_HALT; SW_SPST_EVQPE1
SW2: SW_MODE_SEL; SW_SPST_EVQPE1
SW3: SWITCH_SPDT
U1, U2: MCP6004; SOIC-14_3.9x8.7mm_Pitch1.27mm
U3: BEAGLEBONEBLACK; beagleboneblack_nomount
U4: OKI_7805; Socket_Strip_Angled_1x03

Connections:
/A_FILT_OUT0: J2.2 (T), R38.1
/A_FILT_OUT1: J2.3 (R), R35.1
/A_FILT_OUT2: J1.3 (R), R37.1
/A_FILT_OUT3: J3.2 (T), R36.1
/A_FILT_OUT4: J3.3 (R), R39.1
/A_FILT_OUT5: J1.2 (T), R40.1
/BELA_IN0: P1.1 (AIN_0)
/BELA_IN1: P1.2 (AIN_1)
/BELA_IN2: P1.3 (AIN_2)
/BELA_IN3: P1.4 (AIN_3)
/BELA_IN4: P1.5 (AIN_4)
/BELA_IN5: P1.6 (AIN_5)
/BELA_IN6: P1.7 (AIN_6)
/BELA_IN7: P1.8 (AIN_7)
/BELA_OUT0: P4.1 (AOUT_0), R9.2, R27.1
/BELA_OUT1: P4.2 (AOUT_1), R8.2, R22.1
/BELA_OUT2: P4.3 (AOUT_2), R4.2, R20.1
/BELA_OUT3: P4.4 (AOUT_3), R5.2, R18.1
/BELA_OUT4: P4.5 (AOUT_4), R13.2, R29.1
/BELA_OUT5: P4.6 (AOUT_5), R14.2, R31.1
/BELA_OUT6: P4.7 (AOUT_6)
/BELA_OUT7: P4.8 (AOUT_7)
/D0: R12.1, SW2.2, U3.B7 (TIMER4)
/D1: U3.B8 (TIMER7)
/D2: P2.2, U3.B9 (TIMER5)
/D3: P2.4, U3.B10 (TIMER6)
/D4: P2.6, U3.B11 (GPIO1_13)
/D5: P2.8, U3.B12 (GPIO1_12)
/D6: U3.C12 (GPIO1_28)
/D7: U3.C14 (EHRPWM1A)
/D8: P6.4, U3.B15 (GPIO1_15)
/D9: P6.5, U3.B16 (GPIO1_14)
/D10: U3.C16 (EHRPWM1B)
/D11: P6.2, U3.B18 (GPIO2_1)
/D12: U3.B27 (GPIO2_22)
/D13: U3.B28 (GPIO2_24)
/D14: U3.B29 (GPIO2_23)
/D15: U3.B30 (GPIO2_25)
/RX: P2.3, U3.B38 (UART5_RXD)
/TX: P2.5, U3.B37 (UART5_TXD)
/~HALT: R1.1, U3.C27 (GPIO3_19)
BAT_11.1V: C21.1, C23.1, P3.2, P5.2, U4.1 (VI)
GND: C5.2, C20.2, C21.2, C22.2, C23.2, C24.2, P2.7, P3.1, P5.1, P6.3, P7.3, R12.2, R42.1, SW1.1, SW3.3, U1.11 (V-), U2.11 (V-), U3.B1 (DGND), U3.B2 (DGND), U3.C1 (DGND), U3.C2 (DGND), U3.C43 (DGND), U3.C44 (DGND), U3.C45 (DGND), U3.C46 (DGND), U4.2 (GND)
GNDA: FB1.2, J1.1 (S), J2.1 (S), J3.1 (S), R3.2, R18.2, R20.2, R22.2, R23.2, R24.2, R25.2, R27.2, R29.2, R31.2, R32.2, R33.2, R34.2
unnamed: C1.1, R6.1, U1.3 (+)
unnamed: C2.1, R7.1, U1.5 (+)
unnamed: C3.1, C6.1, U1.1, U1.2 (-)
unnamed: C3.2, R4.1, R6.2
unnamed: C4.1, C7.1, U1.6 (-), U1.7
unnamed: C4.2, R5.1, R7.2
unnamed: C6.2, R21.2
unnamed: C7.2, R19.2
unnamed: C8.1, R10.1, U1.10 (+)
unnamed: C9.1, R11.1, U1.12 (+)
unnamed: C10.1, C12.1, U1.8, U1.9 (-)
unnamed: C10.2, R8.1, R10.2
unnamed: C11.1, C13.1, U1.13 (-), U1.14
unnamed: C11.2, R9.1, R11.2
unnamed: C12.2, R17.1
unnamed: C13.2, R26.2
unnamed: C14.1, R15.1, U2.3 (+)
unnamed: C15.1, R16.1, U2.5 (+)
unnamed: C16.1, C18.1, U2.1, U2.2 (-)
unnamed: C16.2, R13.1, R15.2
unnamed: C17.1, C19.1, U2.6 (-), U2.7
unnamed: C17.2, R14.1, R16.2
unnamed: C18.2, R30.2
unnamed: C19.2, R28.2
unnamed: D1.1 (GRN), P7.4
unnamed: D1.2 (COM), R42.2
unnamed: D1.3 (RED), P7.5
unnamed: FB1.1, P4.10 (GND)
unnamed: P7.1, SW3.1
unnamed: P7.2, R41.2
unnamed: R1.2, SW1.2
unnamed: R2.2, R3.1, U2.10 (+)
unnamed: R17.2, R24.1, R35.2
unnamed: R19.1, R25.1, R36.2
unnamed: R21.1, R23.1, R37.2
unnamed: R26.1, R32.1, R38.2
unnamed: R28.1, R33.1, R40.2
unnamed: R30.1, R34.1, R39.2
unnamed: R41.1, SW3.2
RAW_5V: C22.1, C24.1, P2.1, U3.C5 (VDD_5V), U3.C6 (VDD_5V), U4.3 (VO)
REF_1.8V: C1.2, C2.2, C8.2, C9.2, C14.2, C15.2, U2.8, U2.9 (-)
SYS_3.3V: P6.1, SW2.1, U3.C4 (VDD_3V3EXP)
SYS_5V: C5.1, C20.1, FB2.1, U1.4 (V+), U2.4 (V+), U3.C7 (SYS_5V)
VCC: FB2.2, R2.1

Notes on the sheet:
Voltage Ref
Idle Switch & LED Board

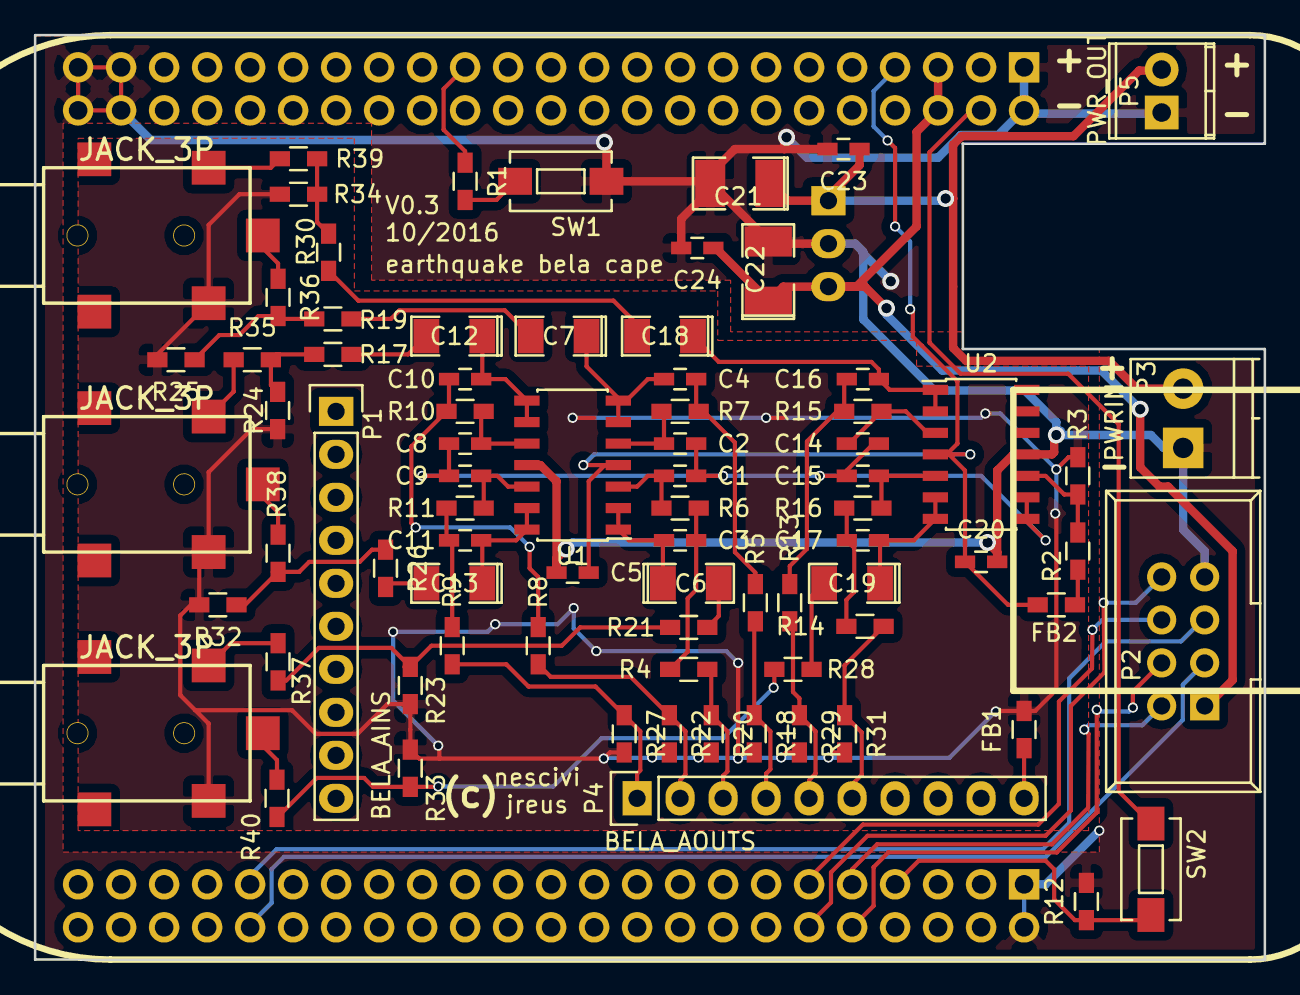
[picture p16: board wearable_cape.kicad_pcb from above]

Board: 2 copper layers, 72.6 x 54.6 mm, 80 parts (1 on the bottom side), 61 nets.

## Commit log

2016-09-22 added new library components and beginning of schematic for filters and connectors
2016-10-04 schematic updates
    [wearable_cape.sch]
2016-10-19 Updates to pcb: use beagleboneblack part in schematic, update the parts that did not have proper references, import all footprints to the pcb
    [wearable_cape.kicad_pcb, wearable_cape.sch]
2016-10-19 basic routing done
    [wearable_cape.kicad_pcb, wearable_cape.sch]
2016-10-19 added zones
    [wearable_cape.kicad_pcb]
2016-10-19 Updates to PCB and first BOM files
    [wearable_cape.kicad_pcb, wearable_cape.sch, wearable_cape_BOM.ods]
2016-10-19 Gerber files
    [wearable_cape-B.Cu.gbr, wearable_cape-B.Mask.gbr, wearable_cape-B.Paste.gbr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]
2016-10-19 Fill in zones better
    [wearable_cape-B.Cu.gbr, wearable_cape-B.Mask.gbr, wearable_cape-B.Paste.gbr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]
2016-10-20 updates to BOM
    [wearable_cape_BOM.ods]
2016-10-20 added new simulations for attenuating filter
2016-10-20 added bode plot of new filter
2016-10-20 updates to pcb: add attenuation, add headphone jacks, fix power supply opamps
    [wearable_cape.kicad_pcb, wearable_cape.sch]
2016-10-20 Update gerber files with latest version of pcb
    [wearable_cape-B.Cu.gbr, wearable_cape-B.Mask.gbr, wearable_cape-B.Paste.gbr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]
2016-10-20 small update to pcb, updates to BOM
    [wearable_cape.kicad_pcb, wearable_cape_BOM.ods]
2016-10-20 updated gerbers
    [wearable_cape-B.Cu.gbr, wearable_cape-B.Mask.gbr, wearable_cape-B.Paste.gbr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]
2016-10-20 more updates to PCB
    [wearable_cape.kicad_pcb]
2016-10-20 update BOM
    [wearable_cape_BOM.ods]
2016-10-20 add non plated holes gerber file
    [wearable_cape-NPTH.drl]
2016-10-20 updated simulation with transient analysis of latest filter design
2016-10-21 add ferrite beads, and fix GNDA -> 1.8_VREF
    [wearable_cape.kicad_pcb, wearable_cape.sch]
2016-10-21 updates to the BOM
    [wearable_cape_BOM.ods]
2016-10-21 updates: footprint check, cutout for regulator, larger power input screw terminal
    [wearable_cape.kicad_pcb, wearable_cape.sch]
2016-10-21 kicad module for OKI regulator outline
2016-10-21 update of the gerber files; v0.2a; uploaded to EuroCircuits
    [wearable_cape-B.Cu.gbr, wearable_cape-B.Mask.gbr, wearable_cape-B.Paste.gbr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]
2016-10-24 added several options for attenuation of circuit.
    [wearable_cape.kicad_pcb, wearable_cape.sch]
2016-10-24 gerbers for latest changes; version 0.3
    [wearable_cape-B.Cu.gbr, wearable_cape-B.Mask.gbr, wearable_cape-B.Paste.gbr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]
2016-10-24 filter simulations for 3V peak2peak attenuation
2016-11-16 rename to .csv of bom list
    [wearable_cape.csv]
2016-11-16 small updates to kicad project
2016-11-16 updates to BOM spreadsheet
    [wearable_cape_BOM.ods]
2016-11-16 Make a note of which mistakes there were on v0.3 of the pcb
2017-03-06 renamed gerber folder to be board version specific
    [wearable_cape-B.Cu.gbr, wearable_cape-B.Mask.gbr, wearable_cape-B.Paste.gbr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]
2017-03-06 version-specific gerbers folder
    [wearable_cape-B.Cu.gbr, wearable_cape-B.Mask.gbr, wearable_cape-B.Paste.gbr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]
2017-03-06 reference pdfs for schematics & PCB
2017-03-06 fixed minijack connections in schematic
    [wearable_cape.sch]
2018-02-24 added MAX6100 1.8v reference datasheet & annotated PCB design
2018-02-28 put schematic in with the matching gerbers.
2018-02-28 fixed jack plugs pinout and made numbering of outputs consistent.
    [wearable_cape.kicad_pcb, wearable_cape.sch]
